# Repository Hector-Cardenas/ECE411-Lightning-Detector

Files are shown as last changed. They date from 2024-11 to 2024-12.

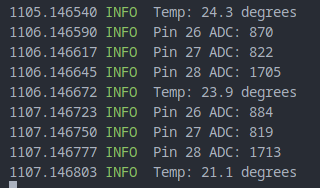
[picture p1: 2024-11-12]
images/transmit.png

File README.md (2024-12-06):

Github Repo for the lightning detector, AKA the THUNDER BUDDY.

All source code downloads require installation of the pico-sdk, instructions can be found at https://www.raspberrypi.com/news/get-started-with-raspberry-pi-pico-series-and-vs-code/ \
Building and compiling was done on a linux machine to produce a .uf2 file to drag and drop into the pico w when in BOOTSEL mode. This is the recommended way to build the project\
For Linux terminal use:\
Clone this repo\
cd ECE411-THUNDER-BUDDIES/software/src\
mkdir build\
cd build\
cmake ..\
make ThunderBuddy\
Drag and drop the .uf2 file into the pico w 

Re-making the project just requires a Make clean and a Make Thunderbuddy
If any of the debug options want to be added or removed one must remove the CMakeCache.txt file in /build before using a new cmake command

CMake options (set the option to =1 to select the argument):\
-DPRINT will print messages to stdout\
-DFLASH will flash the onboard LED when transmitting\
-DFORCE will force an lightning detected condition always\
-DPRINTFLASH combines flash and print\
-DPRINTFORCE combines force and print\
-DDEBUG enables all debug modes\

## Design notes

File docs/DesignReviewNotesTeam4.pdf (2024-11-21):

Design review notes from Team 1 members Chris Kane-Pardy and Caleb Monti; __PDS__
Q: How are you going to test at 60 miles?
A: We are going to do our best using the test system (Marx generator) to see what kind of range we have. Not a must.

Q: Is external power 120V from wall?
A: External power will be USB

__SCHEMATIC__
__POWER BLOCK__
Q: What power supply are you using A: Boost converter for sub 5V inputs

__RF INPUT__
Q: What is J3?
A: Test Header/Manufacturer provided Eval board connection

Q: Is J2 for antenna?
A: any RF input device, likely antenna

__MAIN BOARD__
Q: Why is PDS uC listed as STM32?
A: Change was made and PDS not updated; will fix

Q: Are unused pins NCs?
A: They will be yes

Q: What bus used for transceiver?
A: SPI

Q: Are there any test points on the PCB for J4? A: Plan on using solder holes as test points

Comment: Should put NCs on all floating pins

__PCB__

Q: Will we label pins on PCB or just trust PICO pinout?
A: PICO pinout is labeled

Comment: Should add silkscreen for labeling on various pinouts

Comment: J3 pinout missing a trace

Comment: Some traces may be a bit close together; most close traces are low frequency. Will try to separate if possible

Comment: SILKSCREEN AGAIN! - result of designing for EPL PCB.

Q: How do we plan on mounting?
A: We should add mounting holes!

Comment: Need to add traces for Display even if we don't use it.

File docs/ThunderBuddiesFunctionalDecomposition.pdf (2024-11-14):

## Functional Decomposition for THUNDER BUDDIES

2024-11-13
Team #4
Team Members:
Hector Cardenas, Riley Cox, Nathaniel Fraly, Ishaan Agrawal

Block Diagrams:

Level 0:

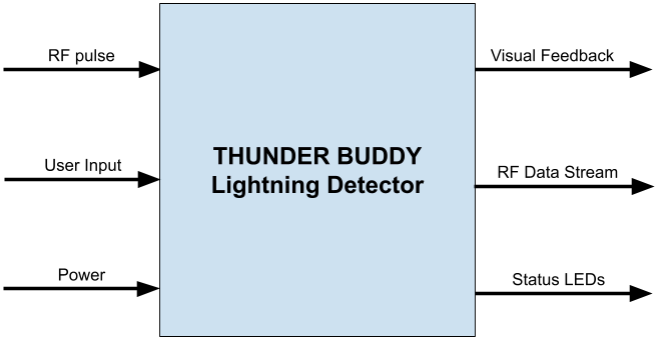
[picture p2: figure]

Figure 1: Block Box diagram; level 0 functional decomposition

Module | THUNDER BUDDY Lightning Detector
Inputs | RF Pulse: Peak Between 5-10 kHz for lightning User Input: Buttons, 2 potentiometers Power: 5V-12V DC
Outputs | Visual Feedback: TFT LCD RF Data Stream: 431-478 MHz; serial data for device ID Status LEDs: Power and Status; Red and Green
Functionality | Notify the user of detected RF pulse representative of a lightning strike near the device. RF data stream configuration can adjust transmission frequency, and the device will transmit its ID tag to a master receiver.

Level 1:

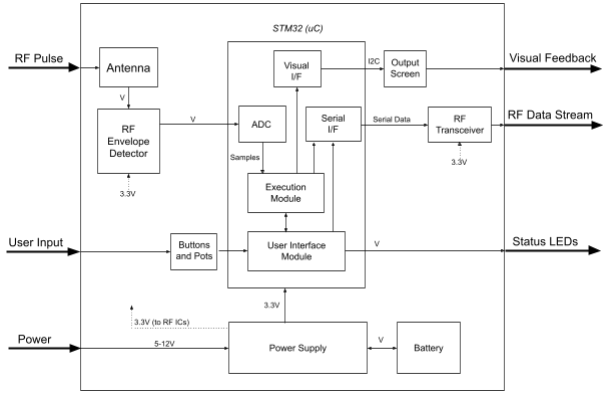
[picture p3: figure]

Figure 2: Block Box diagram; level 1 functional decomposition

Module | Antenna
Inputs | RF Pulse: Peak Between 5kHz-10kHz for lightning
Outputs | Voltage: Max peak of 3.6V
Functionality | Receives RF signal and passes voltage to RF detector chip.
Module | RF Envelope Detector (LMH2121)
Inputs | Voltage: Max peak of 3.6V
Outputs | Voltage: 20mV-2.7V
Functionality | Converts RF signal to linear DC output. When correctly calibrated, should only respond to lighting strikes and ignore other sources of RF noise.
Module | ADC
Inputs | Voltage: 20mV-2.7V
Outputs | Samples: 12 bit resolution
Functionality | Converts analog voltage reading to digital value.

Module | Execution Module
Inputs | Samples: 12 bit resolution Data: Configuration details from UI module
Outputs | Data: Status information to UI module Function calls to visual I/F Function calls to serial I/F
Functionality | Waits for RF interrupt to check if ADC sample is in line with expected lightning strike values. If lightning is detected, it communicates with the other software modules.
Modules | User Interface Module
Inputs | Voltage: 0V-3.3V Data: Status information from Execution Module
Outputs | Voltage: 2V for red LED; 3V for green LED Data: Configuration info to serial out I/F
I/F Module | Buttons and Pots
Inputs | User Input: Button presses, potentiometer rotation
Outputs | Voltage: 0V-3.3V
Functionality | Allows the User to turn on the device through a button press, as well as to calibrate and adjust RF input sensitivity and RF output frequency band through the two potentiometers. This module is also responsible for outputting to the two status LEDs.
Module | Output Screen
Inputs | I2C: Display data
Outputs | Visual F/B: Image indicating detected strike
I/F Module | Visual I/F
Inputs | Data: Lightning detected function call
Outputs | I2C: Display data
Functionality | Reacts to detected strike by displaying predetermined notification of lightning strike.

Module | RF Transceiver (ADF7020)
Inputs | Serial Data: Identification ID, Configuration data
Outputs | RF Data Stream: 431-478 MHz; serial data for device ID
I/F Module | Serial I/F
Inputs | Data: Lightning detected or Configure function call
Outputs | Serial Data: Identification ID, Configuration data
Functionality | Reacts to detected strike by transmitting device identification tag on our calibrated frequency band. Also reacts to configuration (on initialization as well) to change chosen frequency band or device ID.
Module | Power Supply
Inputs | Power: External 5-12V DC Voltage: 3.3V from battery
Outputs | Voltage: 3.3V to battery, RF ICs, and STM32
Functionality | Takes in external power to charge internal battery; also responsible for regulating battery power and feeding it to the other circuit elements.
Module | Battery
Inputs | Voltage: 3.3V from power supply
Outputs | Voltage: 3.3V to power supply
Functionality | Stores power from external source to allow device to operate wirelessly in the field.

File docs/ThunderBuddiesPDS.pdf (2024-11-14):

## Practicum Product Design Specification (PDS) Outline for the THUNDER BUDDIES

2023-11-14
Team #4
Team Members:
Hector Cardenas, Riley Cox, Nathaniel Fraly, Ishaan Agrawal

Project Name:
Automated Lightning Detection System

Executive Summary with Concept of Operations:
The Automated Lightning Detection System (ALDS) will detect lightning within 60 miles. The ALDS is designed for anyone holding events in areas where lightning strikes are common or worrisome. By passively detecting RF that is emitted by lightning naturally, the device is able to alert the user of lightning in the area so they can follow their response protocol as needed.

Market Analysis:
The intended users are event organizers and hosts who need to be aware of lightning in the area with a specificity not met by monitoring weather alerts. The ALDS will be able to provide customers with the ability to be aware of dangerously close lightning, to allow them to respond urgently and effectively. While other lightning detection systems exist, their range is typically quite large (100-300 miles), which can cause critical events to be shut down unnecessarily. The price point we are targeting is $200, between rudimentary in-home detection systems and multi-point network style system units.

Requirements:
- MUST: Detect RF energy pulses emitted by lightning strike.
- MUST: Operate without constant external power (have energy storage).
- MUST: Indicate to the user when a lightning strike is detected.
- SHOULD: Differentiate between RF emitted by lightning and RF emitted by other sources.
- SHOULD: Timestamp the incoming lightning strike using a globally synchronized time source (i.e. across multiple similar devices).
- SHOULD: Capture the detected RF power level over time and save a measurement of the power in a time region around the strike.
- MAY: Transmit data off-board using wireless technology.
- MAY: Have a weatherproof enclosure.
- MAY: Extract energy from the external environment for power (i.e. solar).
Revised: 2024-11-14 v0.2 | Page 1 of 3

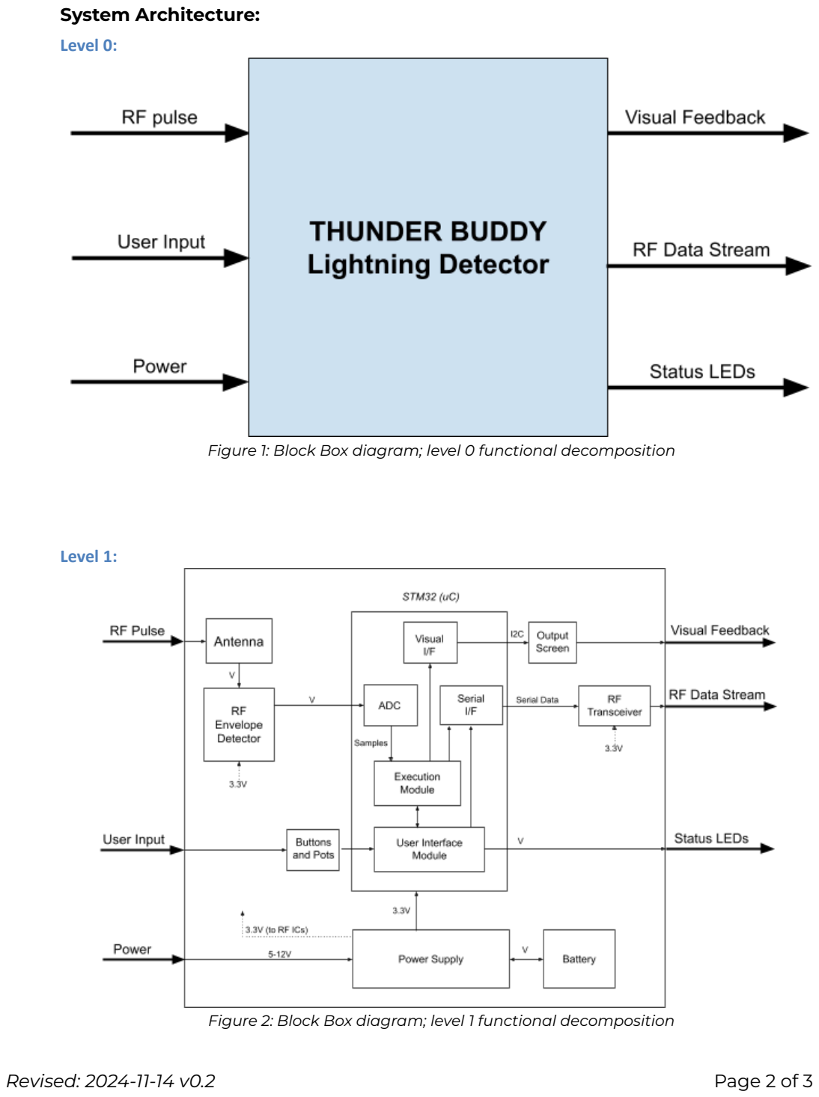
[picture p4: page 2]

System Architecture:

Level 0:

Figure 1: Block Box diagram; level 0 functional decomposition

Level 1:

Figure 2: Block Box diagram; level 1 functional decomposition

Revised: 2024-11-14 v0.2 | Page 2 of 3

Device will notify the user of detected RF pulse representative of a lightning strike near the device; notification is done both visually through a TFT LCD screen as well as a RF transmission of the device’s identification tag. Status LEDs let the user know whether the device is on and whether it needs to be reset. External power is used to charge an internal battery that will then serve to power the device and allow for wireless operation.

Design Specification :
- Sensor: LMH2121 Series RF Power Detector, RF antenna
- Processor: STM32
- Actuator: Status LEDs, TFT LCD screen, ADF7020 ISM Band Transceiver
- Power: ~3.3V Battery
- Mechanical Design: Enclosure that is able to be easily transported
- Development Environment: STM32Cube
- Firmware: STM32 Firmware
Revised: 2024-11-14 v0.2 | Page 3 of 3

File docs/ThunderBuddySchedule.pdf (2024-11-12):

ThunderBuddy | Nov 6, 2024
The ThunderBuddies | https://github.com/Hector-Cardenas/ECE411-Lightning-Detector

Project manager
Project dates | Sep 30, 2024 - Dec 14, 2024
Completion | 0%
Tasks | 25
Resources | 0

Name | Begin date | End date
Team Forming | 9/30/24 | 10/4/24
Project Idea Generation | 10/7/24 | 10/11/24
Create a Product Design Specification | 10/14/24 | 10/18/24
Create a preliminary schematic | 10/21/24 | 10/25/24
Get test breadboard ready for demo | 11/4/24 | 11/6/24
Get schematic updated for Thursday's class | 11/4/24 | 11/6/24
Finalize PDS | 11/7/24 | 11/7/24
Create schedule for Thursday class | 11/4/24 | 11/6/24
Have IO definitions in main.c | 11/4/24 | 11/7/24
Create functions structure for peripherals | 11/4/24 | 11/7/24
Figure out power requirements | 11/4/24 | 11/7/24
How to power the circuit | 11/8/24 | 11/13/24
How to recharge the batteries | 11/8/24 | 11/13/24
Create Bill of Materials | 11/11/24 | 11/14/24
First system integration attempt | 11/18/24 | 11/18/24
System Debug | 11/19/24 | 11/25/24
Second system integration attempt | 11/26/24 | 11/26/24
System Debug 2 | 11/27/24 | 12/3/24
Creata a Functional Decomposition | 11/11/24 | 11/14/24
Create a rough draft of CAD | 11/11/24 | 11/14/24
Finalize CAD | 11/15/24 | 11/20/24
Send board to FAB | 11/21/24 | 11/21/24
Create a test plan | 12/2/24 | 12/5/24
Final Testing | 12/6/24 | 12/12/24
Demo the project | 12/13/24 | 12/13/24
ThunderBuddy | Nov 6, 2024
Tasks | 2

## Gantt Chart

3

Name | Begin date | End date
Team Forming | 9/30/24 | 10/4/24
Project Idea Generation | 10/7/24 | 10/11/24
Create a Product Design Specification | 10/14/24 | 10/18/24
Create a preliminary schematic | 10/21/24 | 10/25/24
Get test breadboard ready for demo | 11/4/24 | 11/6/24
Get schematic updated for Thursday's class | 11/4/24 | 11/6/24
Finalize PDS | 11/7/24 | 11/7/24
Create schedule for Thursday class | 11/4/24 | 11/6/24
Have IO definitions in main.c | 11/4/24 | 11/7/24
Create functions structure for peripherals | 11/4/24 | 11/7/24
Figure out power requirements | 11/4/24 | 11/7/24
How to power the circuit | 11/8/24 | 11/13/24
How to recharge the batteries | 11/8/24 | 11/13/24
Create Bill of Materials | 11/11/24 | 11/14/24
First system integration attempt | 11/18/24 | 11/18/24
System Debug | 11/19/24 | 11/25/24
Second system integration attempt | 11/26/24 | 11/26/24
System Debug 2 | 11/27/24 | 12/3/24
Creata a Functional Decomposition | 11/11/24 | 11/14/24
Create a rough draft of CAD | 11/11/24 | 11/14/24
Finalize CAD | 11/15/24 | 11/20/24
Send board to FAB | 11/21/24 | 11/21/24
Create a test plan | 12/2/24 | 12/5/24
Final Testing | 12/6/24 | 12/12/24
Demo the project | 12/13/24 | 12/13/24
November 2024 | December 2024
4 | 5 | 6 | 7 | 8 | 11 | 12 | 13 | 14 | 15 | 18 | 19 | 20 | 21 | 22 | 25 | 26 | 27 | 28 | 29 | 2 | 3 | 4 | 5 | 6 | 9 | 10 | 11 | 12 | 13

## Resources Chart

4

Name | Default role
4 5 6 7 8 | 11 12 13 14 15 | 18 19 20 21 22 | 25 26 27 28 29 | 2 3 4 5 6 | 9 10 11 12 13

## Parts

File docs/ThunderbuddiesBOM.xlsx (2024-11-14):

Bill Of Materials for: Team 4 Thunderbuddies
Last modified: 2024-11-14
PCB version: v0.1a
BOM revision: v0.1a |  | P/NP | = Place/Not Place (components marked NP are not stuffed on the board)
Cnt | Part References | P/NP | Mfg | Mfg PN | Description | Generic | Dist | Dist Part Number | Cost Ea. | Cost Total
1 | A2 | P | Raspberry Pi | SC0918 | Pico W RP2040-based MCU Board | N | Digikey | 2648-SC0918CT-ND | $6.00 | $6.00
1 | BZ1 | P | Soberton | GT-0903A | 3V Buzzer | Y | Digikey | 433-1032-ND | $0.97 | $0.97
2 | C1, C4 | P | N/A | N/A | 10uF 0603 SMD Ceramic Capacitor | Y | N/A | N/A | $0.25 | $0.50
1 | J1 | P | N/A | N/A | 2.54mm Header, 2 Pins | Y | N/A | N/A | $0.01 | $0.01
1 | J3 | P | N/A | N/A | 2.54mm Header, 3 Pins | Y | N/A | N/A | $0.01 | $0.01
1 | J4 | P | N/A | N/A | 2.54mm Header, 14 Pins, IDC | Y | N/A | N/A | $0.01 | $0.01
1 | L1 | P | N/A | N/A | 1uH Inductor, 1A current carrying capacity | Y | N/A | N/A | $0.25 | $0.25
1 | R3 | P | N/A | N/A | 768k, 1% tolerance | Y | N/A | N/A | $0.10 | $0.10
1 | R4 | P | N/A | N/A | 100k, 1% tolerance | Y | N/A | N/A | $0.10 | $0.10
1 | U3 | P | Texas Instruments | TPS61023DRLR | Boost Switching Regulator IC, Adjustable Output | N | Digikey | 296-TPS61023DRLRCT-ND | $0.89 | $0.89
1 | N/A | P | Analog Devices | EVAL-ADF7020-1DBZ8 | RF Transciever, 128MHz - 142MHz Evaluation Board | N | Digikey | 505-EVAL-ADF7020-1DBZ8-ND | $117.45 | $117.45
1 | N/A | P | Texas Instruments | LMH2121TMEVAL/NOPB | RF Power Detector 100MHz - 3GHz, Evaluation Board | N | Digikey | 296-45776-ND | $118.80 | $118.80
 |  |  |  |  |  |  |  |  |  | $0.00
 |  |  |  |  |  |  |  |  | TOTAL: | $245.09
VERSION INFO
Rev | Date | Notes
0.1a | 2024-11-14 | Initial BOM.

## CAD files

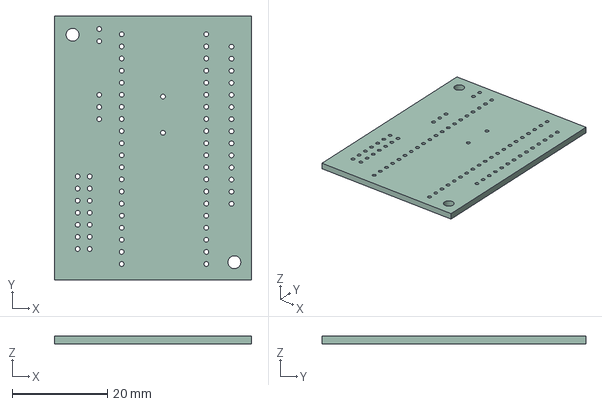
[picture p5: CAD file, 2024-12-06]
kicad/lightning-detector.step
41.4 x 55.4 x 1.60 mm

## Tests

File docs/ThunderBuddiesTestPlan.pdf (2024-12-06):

# Test Plan for the THUNDER BUDDIES

2024-12-02

## Team #4 Hector Cardenas, Riley Cox, Nathaniel Fraly, Ishaan Agrawal

## Unit tests:

Power supply
- Test that power supply provides 3.3V with direct voltage
- Test that battery connection provides 3.3V
- Test that power headers are providing 3.3V

RF Detector
- Show that RF receiver output voltage changes when RF spike is present
- Show that RF receiver output voltage does not spike with background noise

Microcontroller
- Show that firmware loads onto board
- Test that ADC receives input voltage
- Test that Buzzer sounds with code snippet
- Test that TX pin outputs data

RF Transceiver
- *cannot unit test due to chip configuration requirements*

## Verification tests:

- ADC input triggers Buzzer
- ADC input triggers transmission
- TX pin output matches expected Manchester encoded data
- RF pulse exceeds ADC threshold
- RF noise does not exceed ADC threshold
- RF pulse only triggers a single transmission
- RF transceiver receives configuration words over SPI
- RF transceiver sends transmission packet
- RF transmission sends over correct frequency band

## Validation tests:

- Device functions correctly with batteries.
- The device sends a lightning detection notification over radio when lightning is detected.
- The device buzzes when lightning is detected.
- Spurious background emissions should not cause buzzing or detection notifications.
- Lightning detection notifications contain the current time.

2024-12-02

Test Author: Hector Cardenas
Test Case Name: | SPI to RF Transceiver Test #1 | Test ID #: | SPI-to-RF-01
Descripon: | Send SPI signals from microcontroller to RF board; SCLK, SDATA, SEN Verifies that RF board can receive expected configuraon word | Type: | ☑ white box □ black box □ ________

Tester Informaon

| Name of Testers: | Nathan Fraly, Riley Cox | Date: | 2024-12-02
| HW/SW Version: | SW: rev0.8, HW: rev0.2 | Time: | 15:00
| Setup: | Soware compiled in debug mode to loop SPI communicaon
S T E P | Acon | Expected Result | P A S S | F A I L | N / A | Comments
1 | Probe power at PCB header | Output of 3.3V and 0V at 3V3(OUT) and GND pin, respecvely | X
2 | Probe SCLK at PCB header | Output of 1MHz 3.3V square wave clock at SPI0 SCK | X
3 | Analyze SDATA at PCB header | Output of test control word at SPI0 TX | X
4 | Probe SEN at PCB header | Output of a 1ms 3.3V strobe aer each control word at SPI0 CSn | X
5 | Jump power and probe at RF board header | 3.3V and 0V seen at RF VDD and RF GND, respecvely | X
6 | Jump SCLK and probe at RF board header | 1MHz 3.3V square wave clock seen at RF SCLK | | X | | Constant high signal seen at RF CLK
7 | Jump SDATA and analyze at RF board header | Test control word seen at RF SDATA | | | X | Could not test due to failure at A6
8 | Jump SEN and probe at RF board header | 1ms 3.3V strobe aer each control word at RF SLE | | | X | Could not test due to failure at A6
9 | Connect daughter board to Pico headers and analyze logic sent | All signals from A5-A8 should be seen at RF headers | | | X | Could not test due to failure at A6
| Overall test result: | | | X | | Header for 3V3(OUT) mistaken for GND on PCB headers; board likely dead as a result of reverse voltage
2024-12-02 | Page 2 of 3

Example Matrix Test (for varying parameters)

Test Author: Ishaan Agrawal

Test Case Name: | Power System Test | Test ID #: | PWR-01
Descripon: | Test that the boost converter correctly funcons at a variety of power input levels. The power system should operate from a single baery in the 3.0 - 4.3V range and output a steady 5V with +/- 0.5V output tolerance. | Type: | □ white box ☑ black box □ _____________

Tester Informaon

| Name of Tester: | Ishaan Agrawal | Date: | 2024-12-04
| HW/SW Version: | 1.0 | Time:
| Setup: | Use a DC Power supply as a baery and sweep the input voltage in the expected range.
T ES T | INPUT VOLTAGE | EXPECTED OUTPUTS | P A S S | F A I L | N / A | Comments
1 | Apply 2.5V to BATT Header | See 5.0V on 5V rail
2 | 3.0V | See 5.0V on 5V rail
3 | 3.3V | See 5.0V on 5V rail
4 | 3.6V | See 5.0V on 5V rail
5 | 3.7V | See 5.0V on 5V rail
6 | 4.0V | See 5.0V on 5V rail
7 | 4.3V | See 5.0V on 5V rail
| Overall test result:
2024-12-02 | Page 3 of 3

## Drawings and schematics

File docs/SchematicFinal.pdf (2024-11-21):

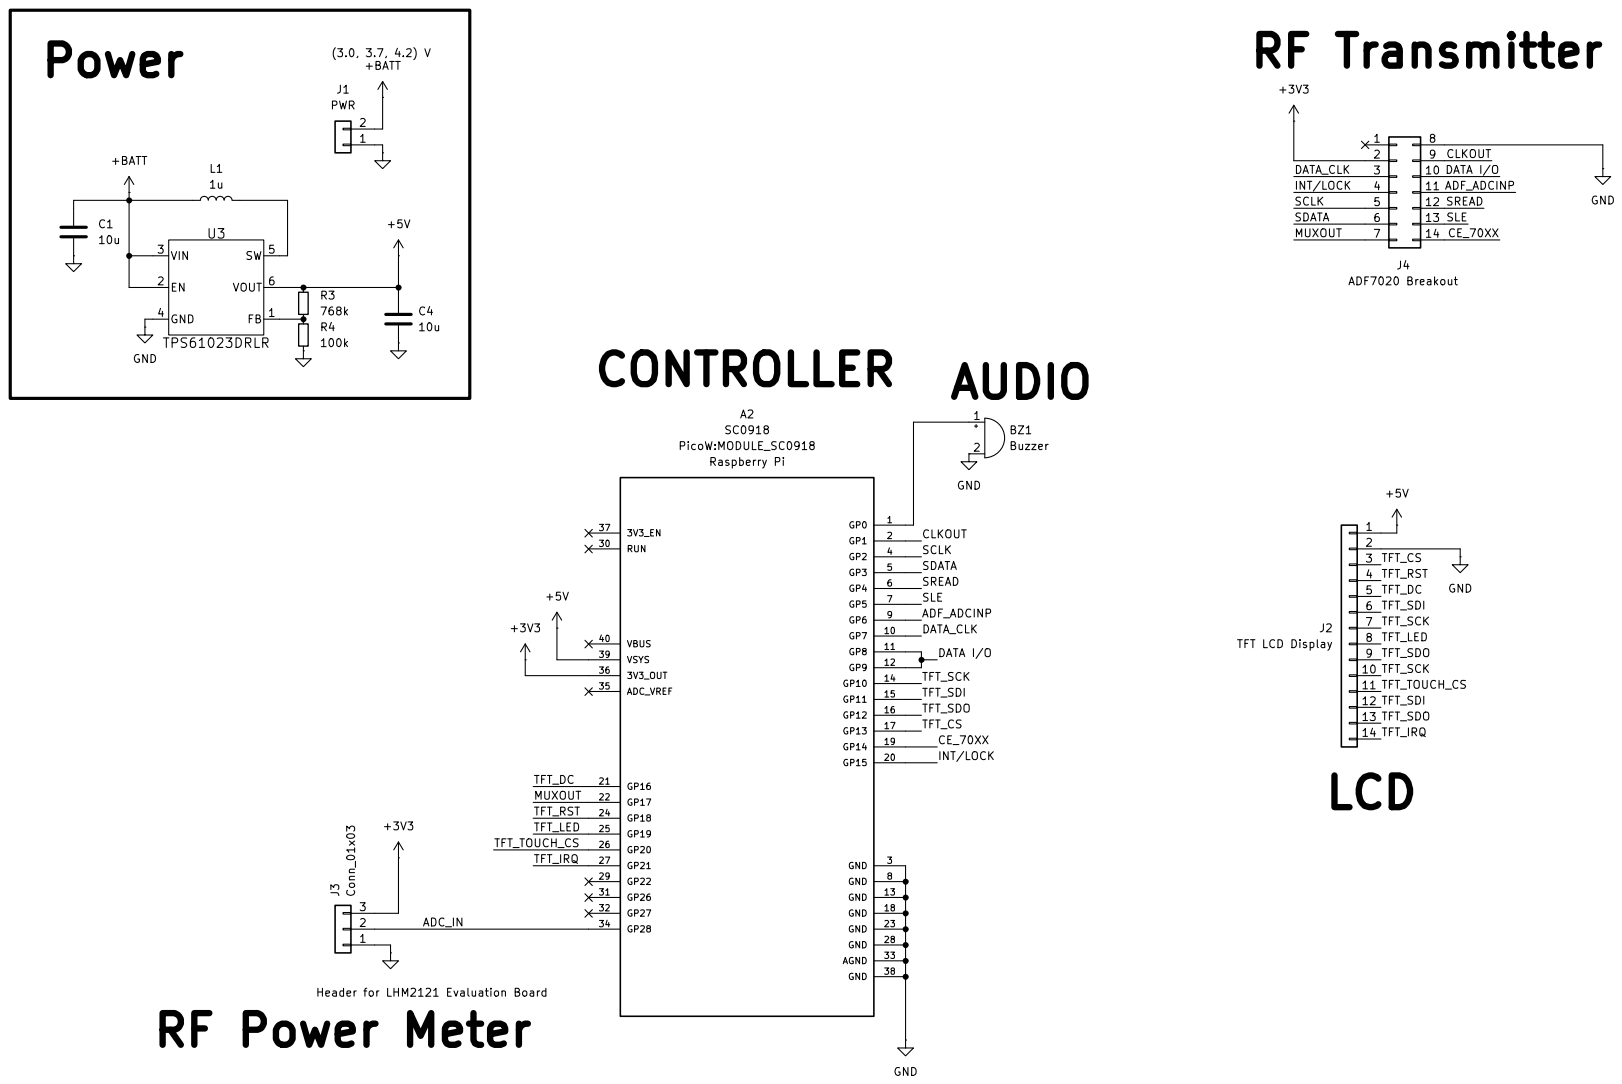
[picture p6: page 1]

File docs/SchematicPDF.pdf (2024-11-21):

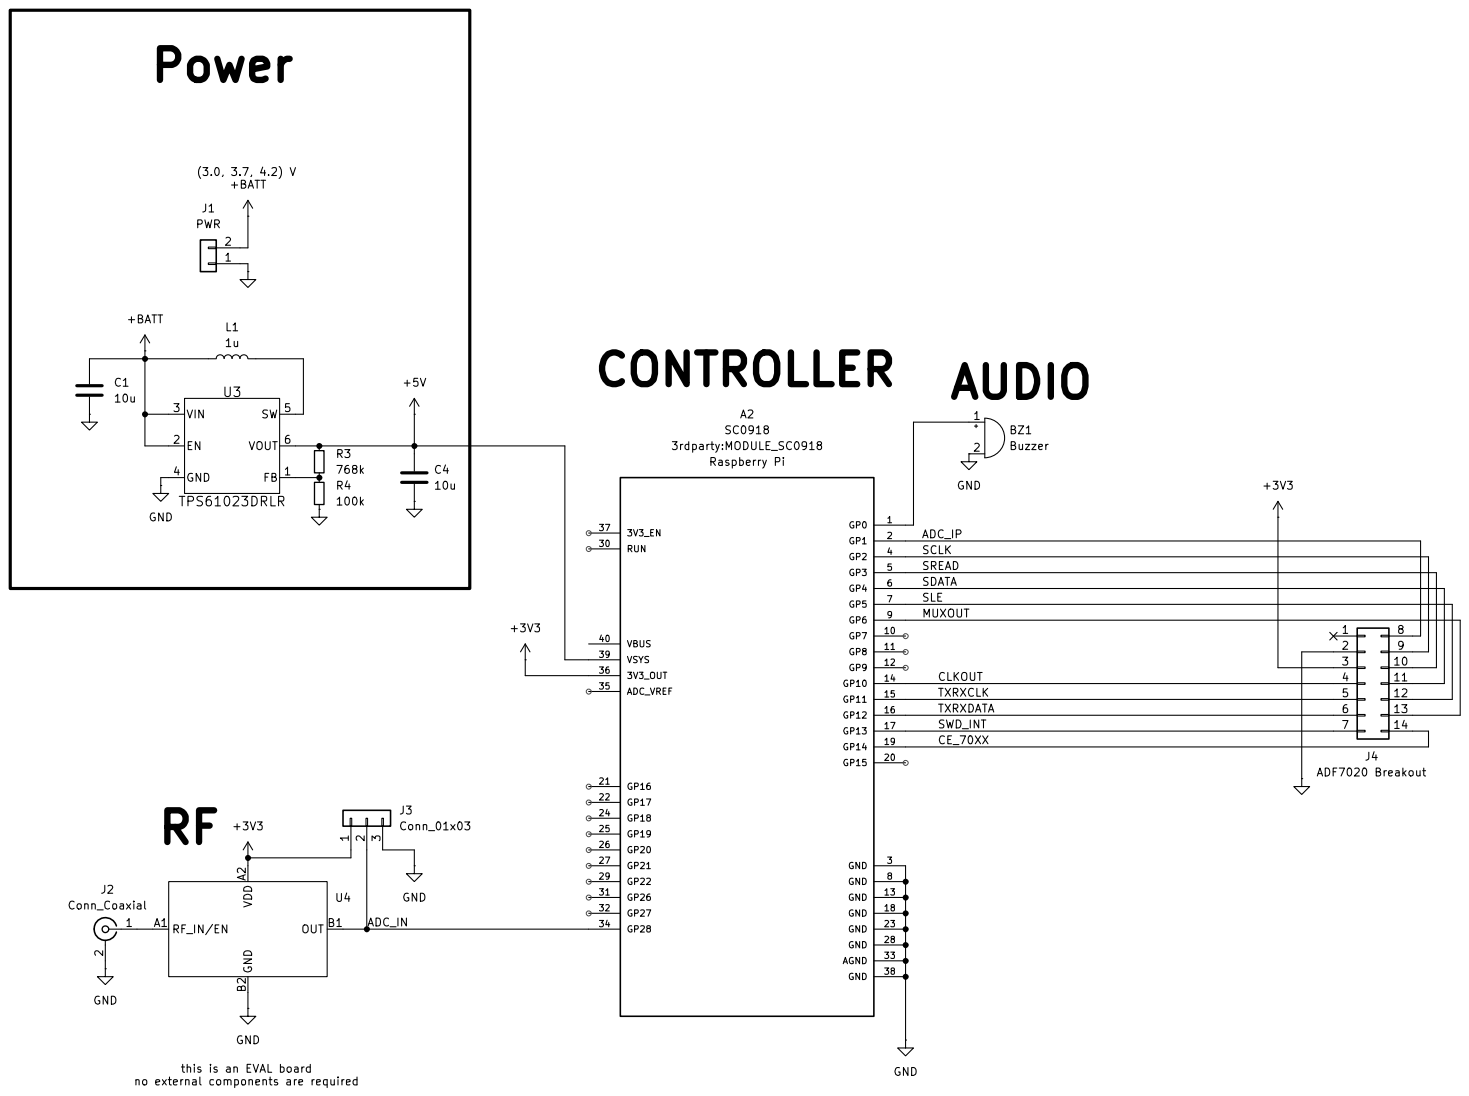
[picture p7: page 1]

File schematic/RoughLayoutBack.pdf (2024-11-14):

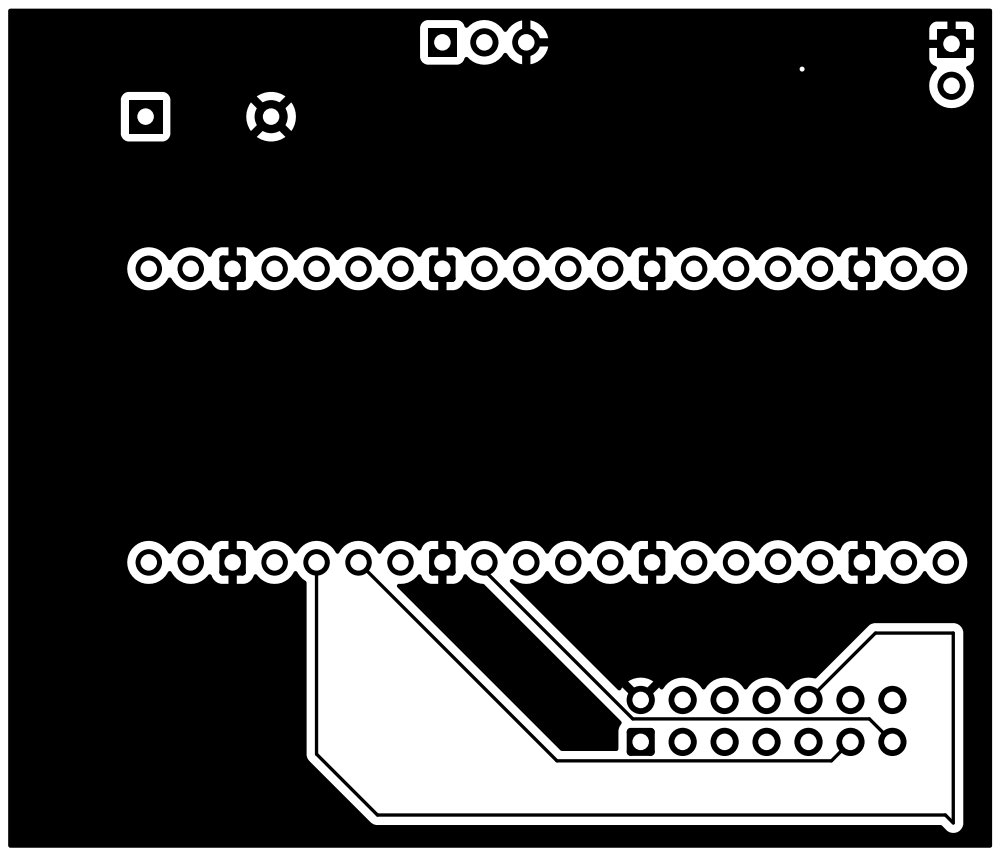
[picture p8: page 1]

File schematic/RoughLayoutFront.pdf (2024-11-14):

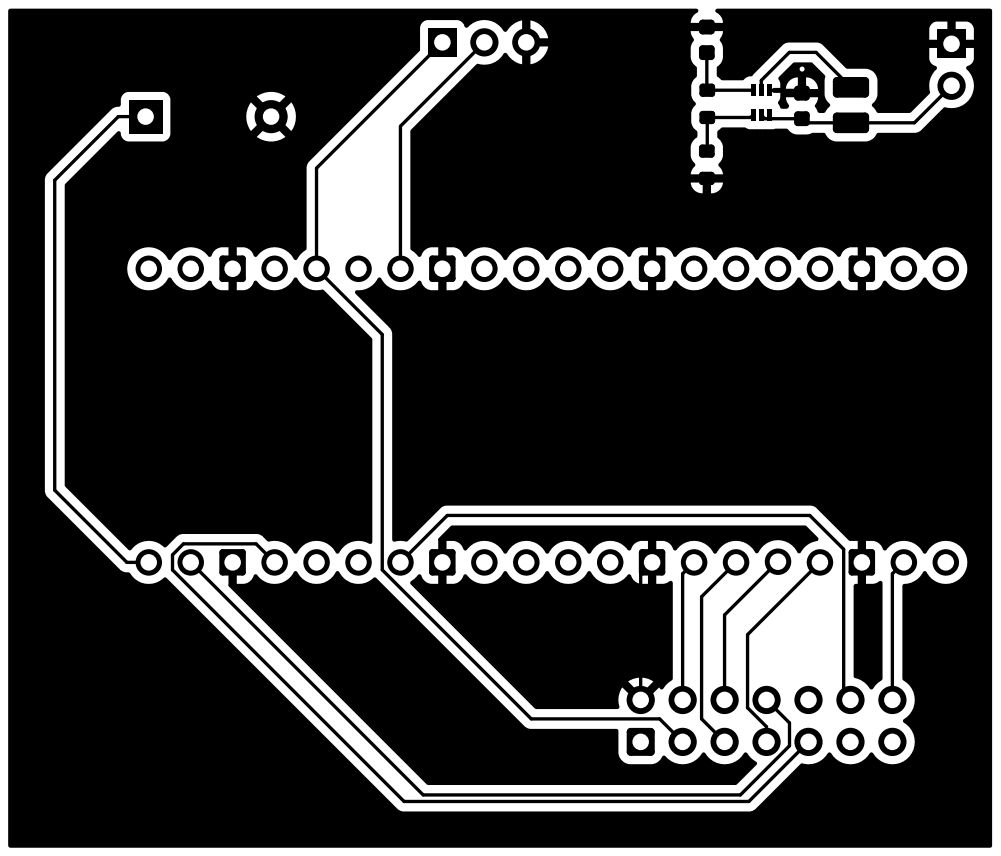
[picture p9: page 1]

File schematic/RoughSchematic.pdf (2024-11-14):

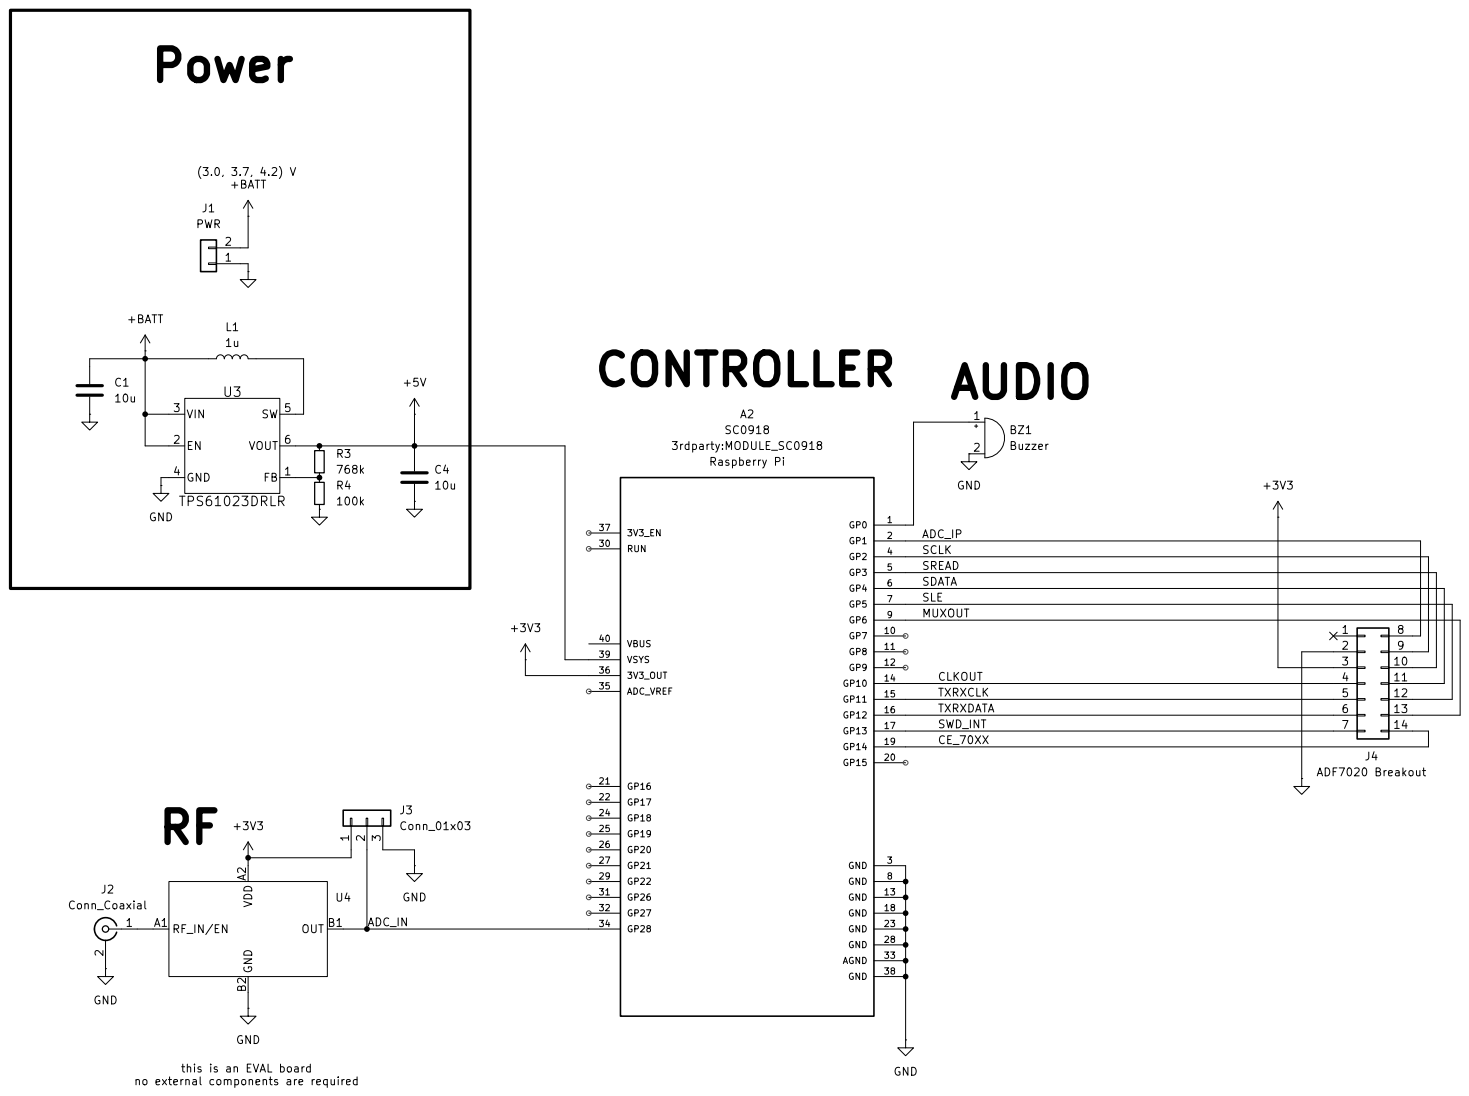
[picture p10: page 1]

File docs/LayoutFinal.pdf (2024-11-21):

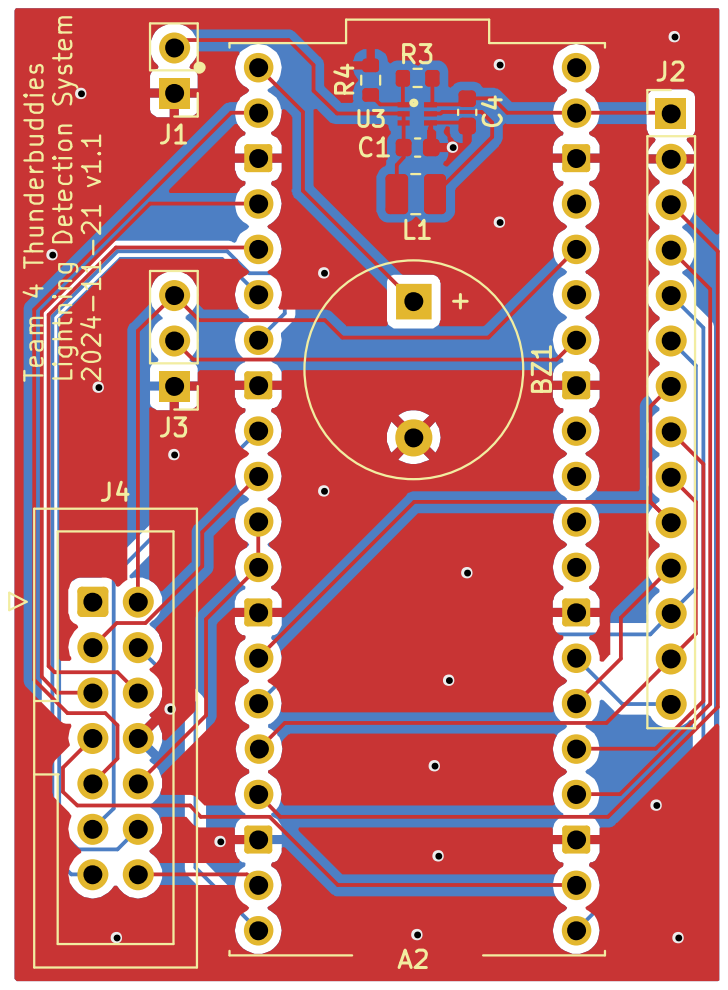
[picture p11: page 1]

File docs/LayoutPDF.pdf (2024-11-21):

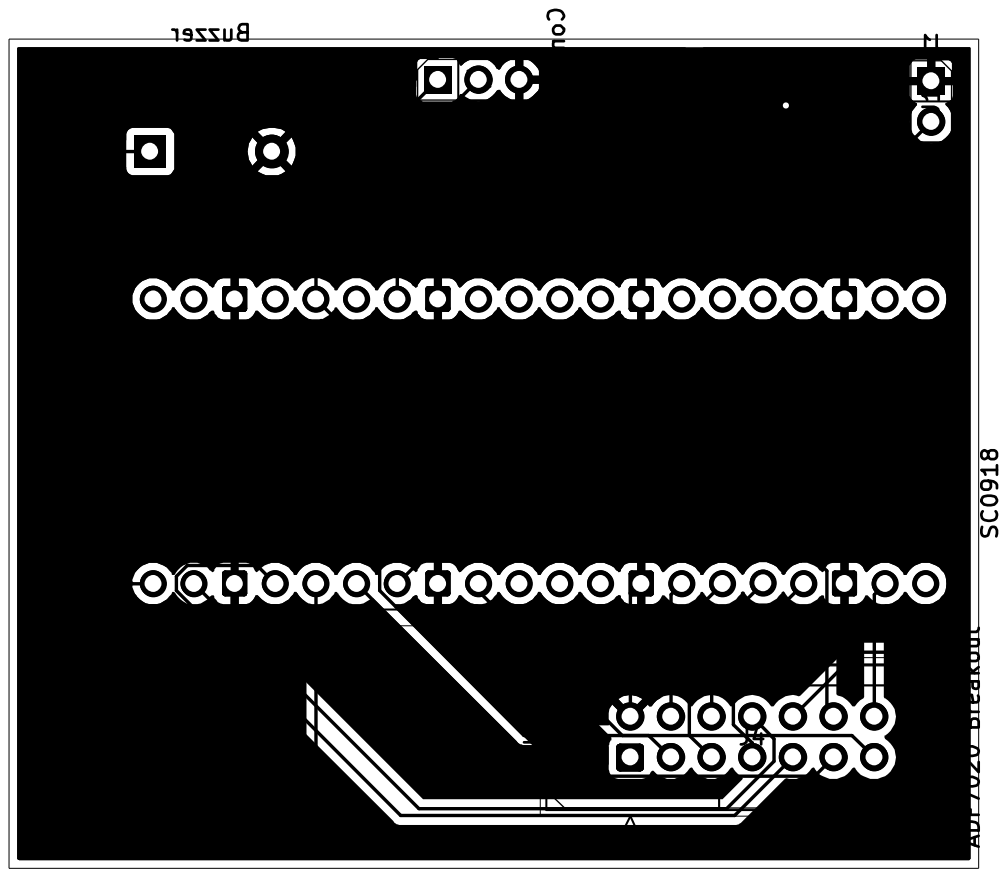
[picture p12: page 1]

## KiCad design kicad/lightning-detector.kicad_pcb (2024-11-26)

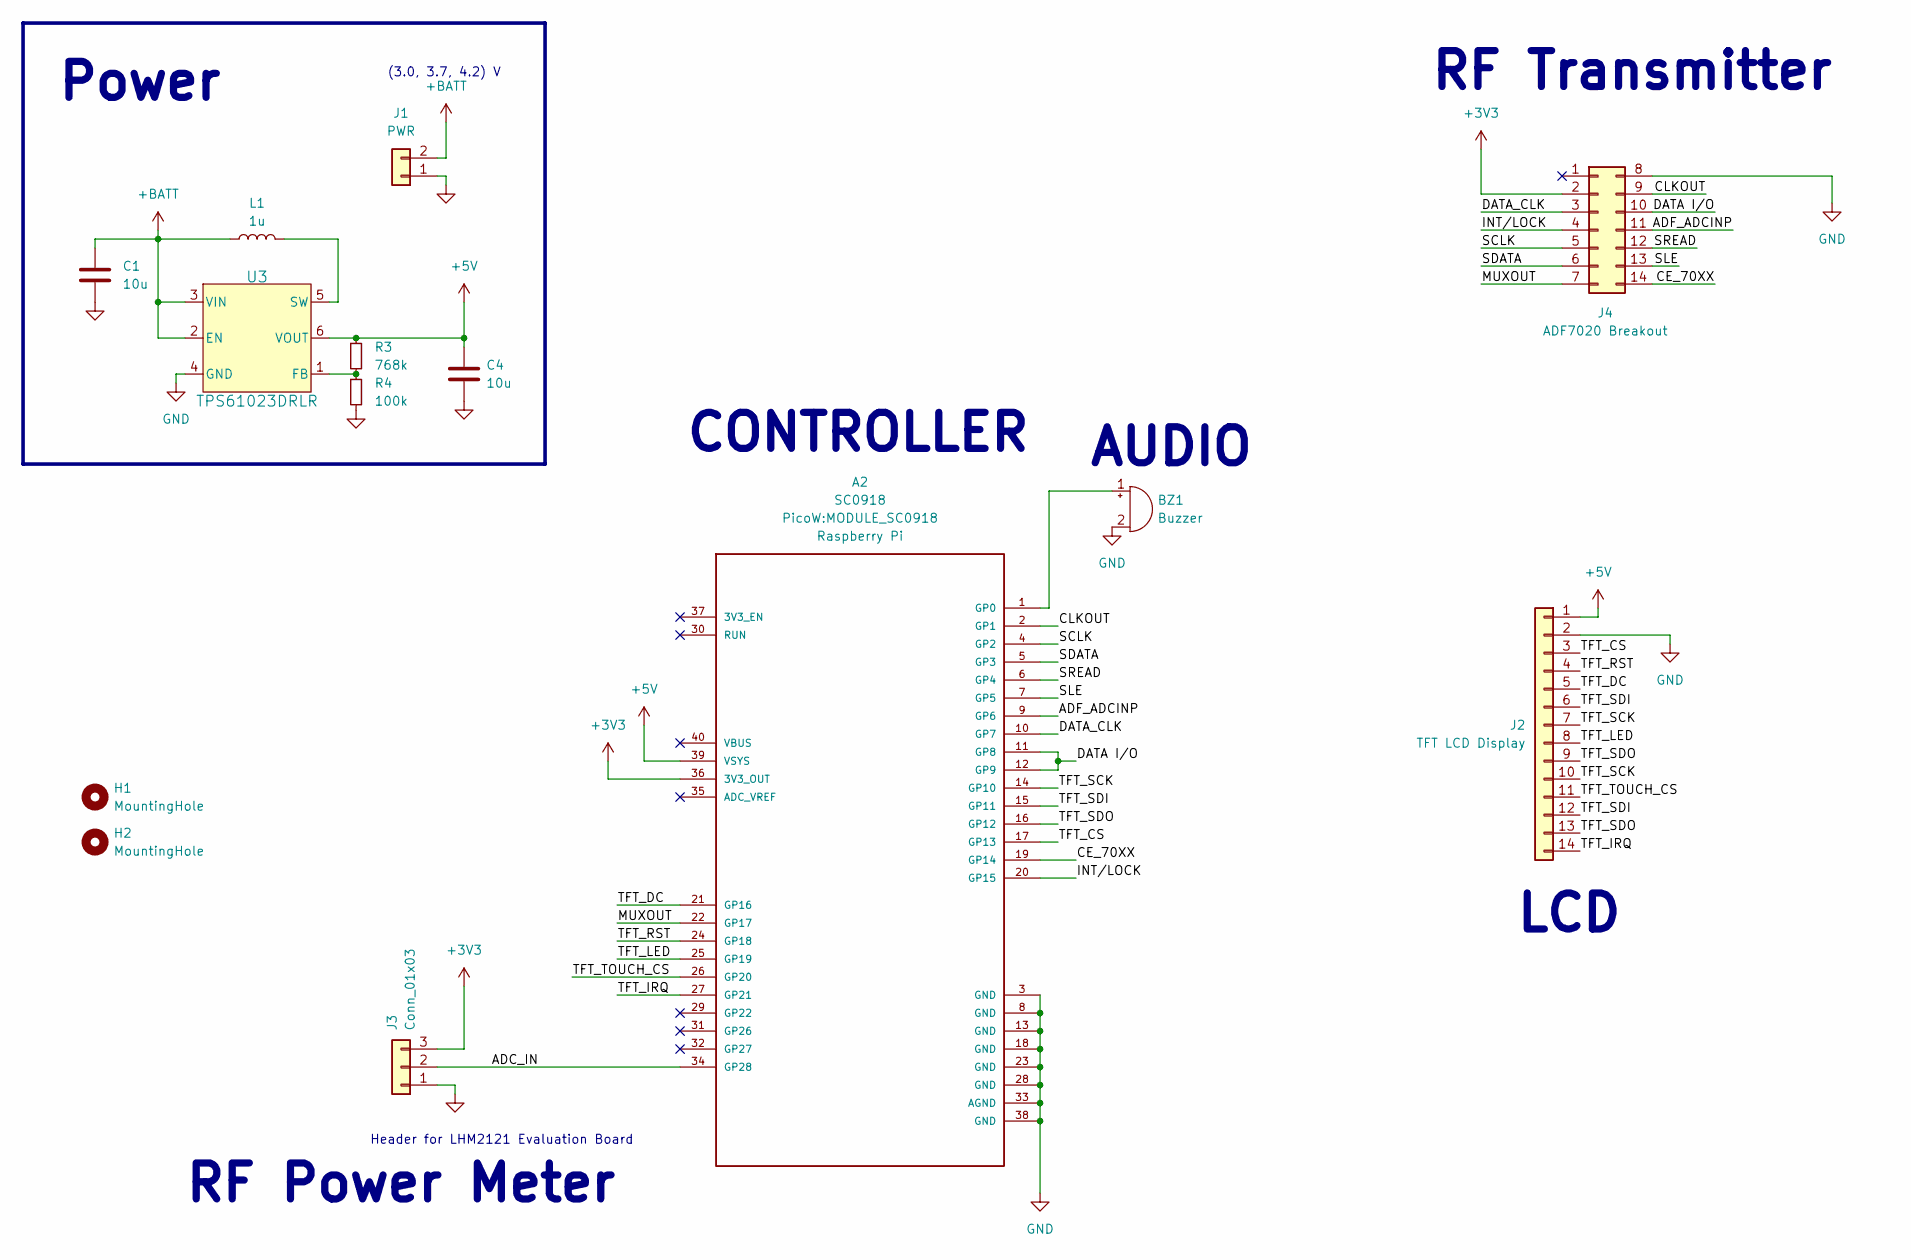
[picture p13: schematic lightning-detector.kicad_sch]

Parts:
A2: SC0918; MODULE_SC0918; PARTREV 1.6
BZ1: Buzzer; Buzzer_12x9.5RM7.6
C1, C4: 10u; C_0603_1608Metric
H1, H2: MountingHole; MountingHole_2.7mm_M2.5
J1: PWR; PinHeader_1x02_P2.54mm_Vertical
J2: TFT LCD Display; PinHeader_1x14_P2.54mm_Vertical
J3: Conn_01x03; PinHeader_1x03_P2.54mm_Vertical
J4: ADF7020 Breakout; IDC-Header_2x07_P2.54mm_Vertical
L1: 1u; L_1008_2520Metric
R3: 768k; R_0603_1608Metric
R4: 100k; R_0603_1608Metric
U3: TPS61023DRLR; SOT563-ORI

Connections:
+3V3: A2.36 (3V3_OUT), J3.3, J4.2
+5V: A2.39 (VSYS), C4.1, J2.1, R3.1, U3.6 (VOUT)
+BATT: C1.1, J1.2, L1.1, U3.2 (EN), U3.3 (VIN)
/ADC_IN: A2.34 (GP28), J3.2
/ADF_ADCINP: A2.9 (GP6), J4.11
/CE_70XX: A2.19 (GP14), J4.14
/CLKOUT: A2.2 (GP1), J4.9
/DATA I/O: A2.11 (GP8), A2.12 (GP9), J4.10
/DATA_CLK: A2.10 (GP7), J4.3
/INT/LOCK: A2.20 (GP15), J4.4
/MUXOUT: A2.22 (GP17), J4.7
/SCLK: A2.4 (GP2), J4.5
/SDATA: A2.5 (GP3), J4.6
/SLE: A2.7 (GP5), J4.13
/SREAD: A2.6 (GP4), J4.12
/TFT_CS: A2.17 (GP13), J2.3
/TFT_DC: A2.21 (GP16), J2.5
/TFT_IRQ: A2.27 (GP21), J2.14
/TFT_LED: A2.25 (GP19), J2.8
/TFT_RST: A2.24 (GP18), J2.4
/TFT_SCK: A2.14 (GP10), J2.7, J2.10
/TFT_SDI: A2.15 (GP11), J2.6, J2.12
/TFT_SDO: A2.16 (GP12), J2.9, J2.13
/TFT_TOUCH_CS: A2.26 (GP20), J2.11
GND: A2.3 (GND), A2.8 (GND), A2.13 (GND), A2.18 (GND), A2.23 (GND), A2.28 (GND), A2.33 (AGND), A2.38 (GND), BZ1.2 (-), C1.2, C4.2, J1.1, J2.2, J3.1, J4.8, R4.2, U3.4 (GND)
unnamed: A2.1 (GP0), BZ1.1 (+)
unnamed: R3.2, R4.1, U3.1 (FB)
unnamed: L1.2, U3.5 (SW)

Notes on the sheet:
LCD
RF Power Meter
AUDIO
Power
CONTROLLER
(3.0, 3.7, 4.2) V
Header for LHM2121 Evaluation Board
RF Transmitter

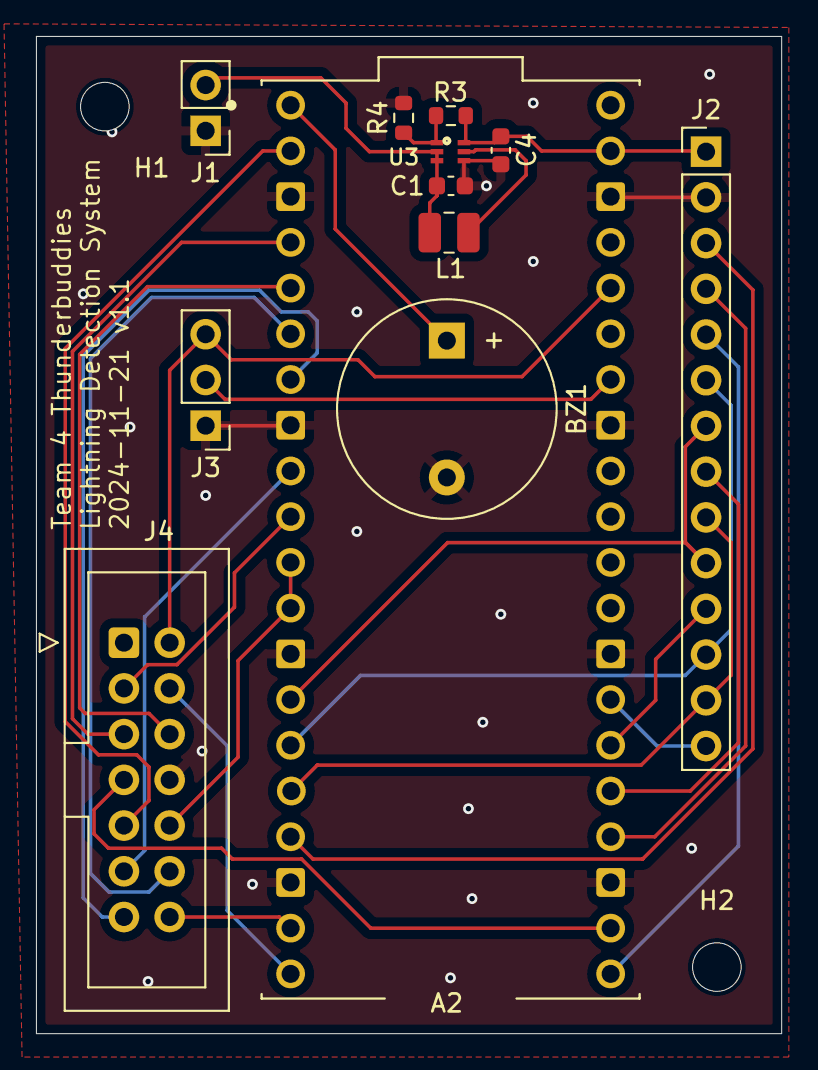
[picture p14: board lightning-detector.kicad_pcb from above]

Board: 2 copper layers, 41.4 x 55.4 mm, 14 parts (0 on the bottom side), 28 nets.

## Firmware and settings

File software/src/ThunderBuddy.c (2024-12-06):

#include <stdio.h>
#include "pico/stdlib.h"
#include "hardware/spi.h"
#include "hardware/i2c.h"
#include "hardware/dma.h"
#include "hardware/adc.h"
#include "hardware/pio.h"
#include "hardware/interp.h"
#include "hardware/timer.h"
#include "hardware/watchdog.h"
#include "hardware/clocks.h"
#include "pico/cyw43_arch.h"
#include "hardware/uart.h"
#include "hardware/irq.h"

#define LED_DELAY_MS 250

//Debug macro expansions
#ifdef PRINTFLASH
#define FLASH
#define PRINT
#endif

#ifdef PRINTFORCE
#define PRINT
#define FORCEINT
#endif

#ifdef DEBUG
#define FLASH
#define PRINT
#define FORCEINT
#endif

// SPI Defines
// We are going to use SPI 0, and allocate it to the following GPIO pins
// Pins can be changed, see the GPIO function select table in the datasheet for information on GPIO assignments
#define SPI_PORT spi0
//#define PIN_MISO 4 
#define PIN_CS 5 
#define PIN_SCK 2 
#define PIN_MOSI 3 

// I2C defines
// This example will use I2C0 on GPIO8 (SDA) and GPIO9 (SCL) running at 400KHz.
// Pins can be changed, see the GPIO function select table in the datasheet for information on GPIO assignments
//#define I2C_PORT i2c0
//#define I2C_SDA 8
//#define I2C_SCL 9

// ADC defines
#define THRESHOLD 0.5
#define ADC_PIN 28
//#define ADC_IRQ 26
#define REFERENCE_VOLTAGE 3.3

// UART defines
// By default the stdout UART is `uart0`, so we will use the second one
#define UART_ID uart1
#define BAUD_RATE 115200

// Use pins 4 and 5 for UART1
// Pins can be changed, see the GPIO function select table in the datasheet for information on GPIO assignments
#define UART_TX_PIN 4
#define UART_RX_PIN 5


#define GPIO14 14

#define BUZZER 0

//ADF7020 defines (Values to be determined)

#define R0 UINT32_C(0x1138DCA0)
#define R1 UINT32_C(0x00021011)
#define R2 UINT32_C(0x20007ED2)

//7020 transmission defines
#define TXRXDATA_PIN 9
#define TX_T         200
#define PREAMBLE     0xAA
#define DEVICE_ID    0x96
#define CALLSIGN     "KK7ETD"
#define CALL_WIDTH   6


// Function declarations
void overThreshold();
void writeRegister(uint32_t data); //Write to device over spi  
void transceiverInit();
void transmit_id();
void txPacket(char packet);
void strobeSPI();

int main()
{
    // IO initialization
    stdio_init_all();
    sleep_ms(5000);
    gpio_init(TXRXDATA_PIN);
    gpio_init(BUZZER);
    gpio_set_dir(BUZZER,GPIO_OUT);
    gpio_set_dir(TXRXDATA_PIN, GPIO_OUT);
    adc_init();
    adc_gpio_init(ADC_PIN);
    adc_select_input(2);
    //gpio_init(PIN_MISO);
    //gpio_init(PIN_SCK);
    //gpio_init(PIN_MOSI);
    uart_init(uart1,9600);
    gpio_set_function(UART_TX_PIN,UART_FUNCSEL_NUM(uart1,UART_TX_PIN));
    
  // variables for ADC conversion
    const float conversion = (REFERENCE_VOLTAGE) / (1 << 12);
    uint16_t rawInput;
    float rfInput;

   // gpio_put(GPIO14,1);
    // SPI initialisation. This example will use SPI at 1MHz.
    /*spi_init(SPI_PORT, 1000 * 1000);
    gpio_set_function(PIN_MISO, GPIO_FUNC_SPI);
    gpio_init(PIN_CS);
    gpio_set_function(PIN_SCK, GPIO_FUNC_SPI);
    gpio_set_function(PIN_MOSI, GPIO_FUNC_SPI);
    spi_set_format(SPI_PORT,16,0,0,SPI_MSB_FIRST);

    gpio_set_dir(PIN_CS, GPIO_OUT);
    gpio_put(PIN_CS, 0);
   */ 
    // Set up WiFi LED 
    if(cyw43_arch_init()){
    printf("WiFi LED initialization failed\n");
    return -1;
    }

    //Initializing transceiver
    #ifdef PRINT
    printf("Initializing transceiver\n");
    #endif
    //transceiverInit();
  

    while (true)
    {
	#ifndef FORCEINT
        rawInput = adc_read();
        rfInput = rawInput * conversion;
	#else
	rfInput = 10;
	#endif
  #ifdef PRINT
      printf("The raw input is %d, rfInput is %f\n",rawInput, rfInput);
  #endif
        if (rfInput > THRESHOLD){
	#ifdef PRINT
	printf("We are checking if the input exceeds the threshold\n");
	#endif
            gpio_put(BUZZER,1);
            overThreshold();
	}
    }
    #ifdef PRINT
    printf("We have left the while loop for some reason");
    #endif
}

//function definitions
void overThreshold(){ // we have gone over our threshold this is where our transceiver/wifi output goes
    #ifdef PRINT
    printf("We are over the threshold, doing something\n");
    #endif
    #ifdef FLASH
    cyw43_arch_gpio_put(CYW43_WL_GPIO_LED_PIN,true); //Set LED to be on
    #endif
    transmit_id();
    sleep_ms(1000);
    #ifdef FLASH
    cyw43_arch_gpio_put(CYW43_WL_GPIO_LED_PIN,false);
    sleep_ms(250);
    #endif
  return;
}

void writeRegister(uint32_t data){ // Sending data over SPI
    #ifdef PRINT
    printf("We are sending %x over SPI\n", data);
    #endif
    uint16_t buffer[2]; //When we send the data over SPI its in one word so we just need to split the word into two halfwords
    buffer[1] = data & 0xFFFF; // Lower bits 
    buffer[0] = (data >> 16) & 0xFFFF; // Upper bits
    spi_write16_blocking(SPI_PORT,buffer,2);
    
    strobeSPI(); 
}

void strobeSPI(){
  gpio_put(PIN_CS,1);
  sleep_ms(1);
  gpio_put(PIN_CS,0);
}

void transceiverInit(){ // Initializing the AD7020 over SPI
    #ifdef PRINT
    printf("We are initializing the 7020 transceiver\n");
    #endif
    writeRegister(R0);
    writeRegister(R0);
    writeRegister(R1);
    writeRegister(R2);
}

void transmit_id(){    
    #ifdef PRINT
    printf("We are transmitting using GPIO from Pico W to 7020\n");
    #endif
    // Transmit  preamble, callsign, and device ID
    char id = DEVICE_ID;
    char callsign[CALL_WIDTH] = CALLSIGN;
    char preamble = PREAMBLE;

    uart_puts(uart1,CALLSIGN);
    // Send message components
    gpio_put(TXRXDATA_PIN,1);
    sleep_ms(250);
    gpio_put(TXRXDATA_PIN,0);
//    txPacket(preamble);
  //  for (int i = 0; i < CALL_WIDTH; i++) txPacket(callsign[i]);
 //   txPacket(id); 

    gpio_put(TXRXDATA_PIN, 0); // Set pin low to mute PA
  return;
}
    

void txPacket(char packet){
    #ifdef PRINT
    printf("We are in the packet transmission function, part of transmit_id\n");
    #endif
    for (int i = sizeof(char)-1; i >= 0; i--) {     
    // Transmit starting from MSB, using IEEE Manchester Code
        gpio_put(TXRXDATA_PIN, (~(packet >> i) & 1)); 
        sleep_ms(TX_T/2);
        gpio_put(TXRXDATA_PIN, ( (packet >> i) & 1));
        sleep_ms(TX_T/2);
    return;
	}
}

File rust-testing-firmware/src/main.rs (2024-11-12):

//! This example test the ADC (Analog to Digital Conversion) of the RS2040 pin 26, 27 and 28.
//! It also reads the temperature sensor in the chip.

#![no_std]
#![no_main]

use defmt::*;
use embassy_executor::Spawner;
use embassy_rp::adc::{Adc, Channel, Config, InterruptHandler};
use embassy_rp::bind_interrupts;
use embassy_rp::gpio::Pull;
use embassy_time::Timer;
use {defmt_rtt as _, panic_probe as _};

bind_interrupts!(struct Irqs {
    ADC_IRQ_FIFO => InterruptHandler;
});

#[embassy_executor::main]
async fn main(_spawner: Spawner) {
    let p = embassy_rp::init(Default::default());
    let mut adc = Adc::new(p.ADC, Irqs, Config::default());

    let mut p26 = Channel::new_pin(p.PIN_26, Pull::None);
    let mut p27 = Channel::new_pin(p.PIN_27, Pull::None);
    let mut p28 = Channel::new_pin(p.PIN_28, Pull::None);
    let mut ts = Channel::new_temp_sensor(p.ADC_TEMP_SENSOR);

    loop {
        let level = adc.read(&mut p26).await.unwrap();
        info!("Pin 26 ADC: {}", level);
        let level = adc.read(&mut p27).await.unwrap();
        info!("Pin 27 ADC: {}", level);
        let level = adc.read(&mut p28).await.unwrap();
        info!("Pin 28 ADC: {}", level);
        let temp = adc.read(&mut ts).await.unwrap();
        info!("Temp: {} degrees", convert_to_celsius(temp));
        Timer::after_secs(1).await;
    }
}

fn convert_to_celsius(raw_temp: u16) -> f32 {
    // According to chapter 4.9.5. Temperature Sensor in RP2040 datasheet
    let temp = 27.0 - (raw_temp as f32 * 3.3 / 4096.0 - 0.706) / 0.001721;
    let sign = if temp < 0.0 { -1.0 } else { 1.0 };
    let rounded_temp_x10: i16 = ((temp * 10.0) + 0.5 * sign) as i16;
    (rounded_temp_x10 as f32) / 10.0
}

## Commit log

2024-10-24 prelim schematic
    [lightning-detector.kicad_pcb, lightning-detector.kicad_sch]
2024-11-07 breadboard prototype
2024-11-07 Updated schematic and created preliminary PCB.
    [lightning-detector.kicad_pcb, lightning-detector.kicad_sch]
2024-11-12 ThunderBuddy interrupt
2024-11-12 Added interrupt to main code
2024-11-14 wk07 items
    [lightning-detector.kicad_pcb, lightning-detector.kicad_sch]
2024-11-14 add bom
    [ThunderbuddiesBOM.xlsx]
2024-11-20 Repo cleanup; added docs and schematic folders for assignment docs and assignment schematics
    [ThunderbuddiesBOM.xlsx]
2024-11-21 Adding PDF versions of schematic and PCB for week 7 assignment
2024-11-21 v1.1, new schematic/pcb
    [lightning-detector.kicad_pcb, lightning-detector.kicad_sch]
2024-11-21 add schematic and layout pdfs
2024-11-23 SPI initialization and environment for linux build and make
2024-11-23 Making config word macros uint32_t type instead of default compile type. SPI functions changed to take uint32_t argument
2024-11-23 Clean up comments, add packet transmission for AD7020 transmitter. Fixed compile issues with packet transmission.
    [ThunderBuddy.c]
2024-11-25 Switched to software interrupt, got LED to flash when over threshold
2024-11-25 Fixed a small issue with an #ifdef
    [ThunderBuddy.c]
2024-11-25 LED flashes when transmit
2024-11-25 Fixed merge conflicts in ThunderBuddy.c
    [ThunderBuddy.c]
2024-11-26 Added newlines to debug print statements
2024-11-26 add mounting holes
    [lightning-detector.kicad_pcb, lightning-detector.kicad_sch]
2024-11-26 Added newlines to debug print statements and added an initial sleep to see the transceiver initialization
2024-12-05 add test plan
    [lightning-detector.step]
2024-12-06 Changes including the UART transmission output and buzzer output
    [ThunderBuddy.c]
